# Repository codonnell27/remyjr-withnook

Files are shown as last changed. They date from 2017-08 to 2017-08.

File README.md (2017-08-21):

# remyjr-withnook
Remy Jr autonomous robot using raspberry pi, nook, and various sensors

## Launching 

If launching on the original remyJr, these are the only necessary steps. If launching on a different system, Dependencies & Setup (see below) has a list of packages that need to be on the raspberry pi and nook, while System Dependent Variables (see below) has a list of variables in the remyJr package code that might need to be changed.

 There are two launch files:
 
 driveremy.launch - Launch file for driving without sounds.
 
 loud_drive.launch - Launch file for driving with sounds. Before launching the output speaker must be manually set. For example:
 
 ```bash
pacmd list-sources | grep -e 'name:'
  name: <alsa_output.usb-C-Media_Electronics_Inc._USB_Audio_Device-00.analog-stereo.monitor>
pacmd set-default-source alsa_output.usb-C-Media_Electronics_Inc._USB_Audio_Device-00.analog-stereo.monitor
pacmd list-sinks | grep -e 'name:'
  name: <alsa_output.usb-C-Media_Electronics_Inc._USB_Audio_Device-00.analog-stereo>
pacmd set-default-sink alsa_output.usb-C-Media_Electronics_Inc._USB_Audio_Device-00.analog-stereo

 ```

To launch one of these files (launch from the nook):
```bash
source devel/setup.bash
roslaunch remyJr driveremy.launch
```

## Dependencies & Setup

The remyJr package needs to be on both the nook and the raspberry pi.

It depends on the ros packages rospy, std-msgs, and sound_play. It also has the following non-ros dependencies for the sensors:

##### BNO055 

This package needs to be on the raspberry pi.

The package used can be found here: https://github.com/adafruit/Adafruit_Python_BNO055    

Adafruit's installation/setup instructions can be found here: https://learn.adafruit.com/bno055-absolute-orientation-sensor-with-raspberry-pi-and-beaglebone-black/overview

##### PCA9685 

This package needs to be on the raspberry pi.

The package used can be found here: https://github.com/adafruit/Adafruit_Python_PCA9685  

Adafruit's setup/installation instructions can be found here: https://learn.adafruit.com/adafruit-16-channel-servo-driver-with-raspberry-pi/overview

##### MCP3008  

This package needs to be on the raspberry pi.

The package used can be found here: https://github.com/adafruit/Adafruit_Python_MCP3008

Adafruit's setup/installation instructions can be found here: https://learn.adafruit.com/raspberry-pi-analog-to-digital-converters/mcp3008

In this project, the software SPI connection from Adafruit's setup instructions was used.

##### VL53L0X 

This package needs to be on the raspberry pi.

The package used can be found here, as well as installation instructions: https://github.com/johnbryanmoore/VL53L0X_rasp_python  

The raspberry pi initially had trouble locating the vl53l0x_python.so file. Creating the directory /home/pi/bin and copying the vl53l0x_python.so file into it fixed the problem.

##### Sounds

Sounds used in the project are stored in the misc folder of remyJr. They must be moved to the sound_play/sounds in the sound_play package on the nook to be played. 

##### Raspberry Pi
 
 SSH and i2c must be enabled on the raspberry pi.

## System Dependent Variables

If this is build on another system, the following variables and files must be changed to reflect the new system's connections:

remyJr/launch/driveremy.launch - The address, username, address to env.sh, and password of the raspberry pi may need to be updated.

remyJr/misc/env.sh - ROS_IP and ROS_MASTER_URI must be changed to reflect the address of the nook. ROS_HOSTNAME must be changed to reflect the address of the pi. This file must also be moved to the the devel directory in the workspace directory on the raspberry pi (ex: ~/catkin_ws/devel).

remyJr/scripts/tof_watch.py - f_shutdown_pin and b_shutdown_pin must be changed to the shutdown pins of the time-of-flight sensors. The floor distance variables may also need to be changed depending on the location of the tof sensors.

remyJr/scripts/sonar_watch.py - The software SPI connection pins must be change to reflect the connections between the raspberry pi and the ADC. ADC channel numbers must be changed to reflect channel connections of the sonars and orientation of the array. Finally, sonar_array_trig_pin must be changed to reflect the raspberry pi pin it is connected to.

remyJr/scripts/imu_watch.py - The reset_pin, level_grav_x, and jump_threshold must be changed to reflect the new setup. 

remyJr/scripts/control_motors.py - drivePin and turnPin must be changed to reflect the connections between the motor drivers and the PCA9658.

remyJr/scripts/bump_watch.py - The software SPI connection pins must be change to reflect the connections between the raspberry pi and the ADC. ADC channel numbers must be changed to reflect channel connections of the Joystick.

## Electrical Components used:

1 Raspberry Pi - used to read sensor data and drive motors

1 Nook - used for decision making and graphic sensor and motion data, since the raspberry pi has limited processing power

8 LV-MaxSonar_EZ1 Sonar sensors - used for object detection and to inform descisions as to which direction the robot should drive

2 MCP3008 ADC - One is used in conjunction with the sonars to convert data into a form readable by the raspberry pi; the other does the same for the joystick

2 VL53L0X time-of-flight sensors - used for cliff detection directly in front and behind the robot

1 BNO055 IMU with sensor fustion - used to determine if the robot is level

1 PCA9685 Servo Motor Driver - used to fake an RC signal that is used to command the motor drivers

1 Sunfounder Joystick - used in conjunction with bump skirt to detect if the robot has hit anything

1 USB speaker (optional) - used to make a squeaky toy noise when the robot hits something

## Circuit 

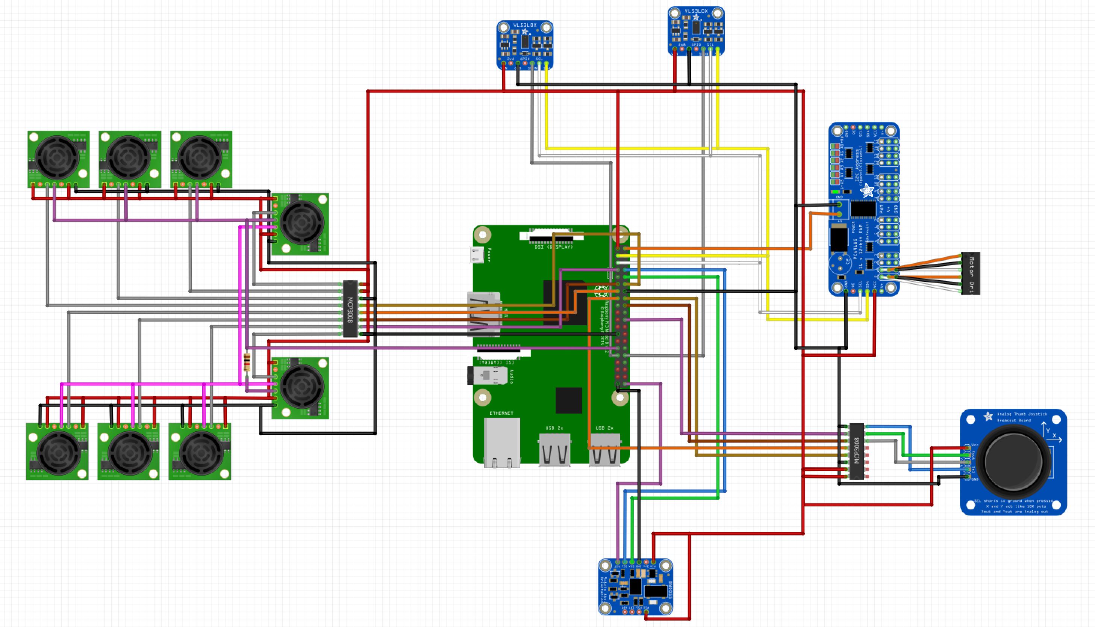
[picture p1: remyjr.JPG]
remyjr circuit diagram


The joystick pictured above is not the joystick used, but it has the same connections.

The sonar array must be arranged so that the sonars facing front, left, right, and back are triggered by the same signal and the sonars facing front right, front left, back left, and back right are triggered by a different signal. This means that no sonar with a purple wire to it's RX pin in the above image should be next to another sonar with a purple RX wire. The same holds true for pink RX wires.

The imu should be placed so that the breakout board is level with the base of the robot and longest sides are on the left and right. (There doesn't seem to be any axis markings on the chip...)

If the raspberry pi is not connected to power via micro usb but the motor drivers are powered, the raspberry pi will power itself via gpio, which leaved it open to frying itself. So be careful when testing the motor drivers that the raspberry pi and PCM9685 is not connected to the motor drivers!

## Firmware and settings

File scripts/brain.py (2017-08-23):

#!/usr/bin/env python
from __future__ import division
from remyJr.msg import sensor_status
from remyJr.msg import imu_data
from remyJr.msg import tof_data
from remyJr.msg import current_activity
from remyJr.msg import sonar_array
from remyJr.msg import graphics_data
from remyJr.msg import bump_data
from remyJr.msg import pwm_val
from remyJr.msg import motor_data
import rospy
import time
import math

# both of these variables correspond to array lengths in sonar_data.msg,
# pwm_val.msg and motor_data.msg
num_of_sonar = 8
pwm_command_queue_len = 50

#PWM values
drive_speed_max = 329
drive_speed_min = 301
drive_speed_zero = 315
# upper and lower bounds of the zero range
# these correspond to the lowest PWM values
# that result in the robot acutally driving
# for some reason these don't result in the same speed???
# for turning, a lower <drive_speed_zero_lowlim PWM value
# will result in a clockwise turn
drive_speed_zero_uplim = 325
drive_speed_zero_lowlim = 305

# together these control how fast the robot accelerates
# accel_const determines the slope of the acceleration curve
# it must be between 0 and 1
# sleep_time (in seconds) determines the time the motors rest between changing PWM values
accel_const = 0.2
sleep_time = 0.07

#determines how fast the robot turns when edgefinding
# edgefind_speed must be between -1 and 1 (a negative number
# will result in the robot turning in the opposite direction)
edgefind_speed = 0.35

# how fast the robot turns when avoiding obstacles
# a smaller value is usually better to avoid overshooting
obstacle_avoidance_speed = 0.1

# the angle the robot tries to keep edges on while edgefinding
right_angle = 90
# these next two values control what the robot considers to be within
# an acceptable range of right_angle
# right_side_width is the number of degrees (centered around right_angle)
# that the robot will consider to be ok when edgefinding
# i.e. when the "edge" is within that range, the robot will drive straight
# instead of turning
right_side_width = 90
right_side_up_lim = (right_angle + (right_side_width/2))
right_side_low_lim = (right_angle -(right_side_width/2))
right_side_opposite = (360-right_angle)

# the robot ignores distances greater than this while edgefinding (in cm)
edge_dis = 100
# distances within this (in cm, so ~1 ft) are not accurately read by the sonar
deadzone = 30
# approx. distance (in cm) that the front sticks out from the front sonar
front_distance = 45
# when the front sonar reads a distance closer than this (in cm)
# the robot won't drive straight. Must be greater then 30cm for accurate reading
tooCloseDis = 60

# this value is compared to how_close to determine if the space is too crowded to edgefind
# how_close is a value (calculated later) between 0 and 1
# 0 being that the robot is in a very confined space and 1 being
# that all sonar are reading a distance greater than edge_dis
# when how_close is less than close_quarters_edgefinding_lim then the robot won't edgefind
# it will just drive straight until it finds and obstacle or it is no longer in such a
# confined space
close_quarters_edgefinding_lim = 0.6

def setup():
	global  motor_change_num, current_l, sonar_dis, x_cord, y_cord, isAvoiding, immediate_danger_f, immediate_danger_b
        global f_sonar, f_r_sonar, r_sonar, b_r_sonar, b_sonar, b_l_sonar, l_sonar, f_l_sonar, tof_drive_ok_f, tof_drive_ok_b
	global avoid_direction_count, avoid_direction, sensor_ok, current_act, is_level, r_bump, l_bump
	global danger_prevented, f_bump, b_bump, current_a, avoidance_count, found_far_away, pwm_command_num, pwm_publish_count, last_pwm_command_num
	#these values represent the order in which seach sonar's data is sent
        f_sonar = 0
        f_r_sonar = 1
        r_sonar = 2
        b_r_sonar = 3
        b_sonar = 4
        b_l_sonar = 5
        l_sonar = 6
        f_l_sonar = 7
	# this is a count to ensure that the robot varies which direction it turns
	# when avoiding obstacles
	avoid_direction_count = 0
	#this indicates the direction the robot will turn when avoiding obstacles
	avoid_direction = 1
	# this count ensures that the robot changes the direction it tries turning periodically
	# only for when it's avoiding obstacles
	# helps keep the robot from getting stuck
	avoidance_count = 0

        rospy.init_node('robot_brain')
        global pub1, pub2, pub3
        pub1=rospy.Publisher('remyjr/motion_data', graphics_data, queue_size=1)
        pub2=rospy.Publisher('remyjr/current_activity', current_activity, queue_size=1)
        pub3=rospy.Publisher('remyjr/pwm_val', pwm_val, queue_size = 3)

	# these keep track of how many pwm commands this node has sent and help other
	# nodes keep track of whether a command has been followed by the robot
	last_pwm_command_num = -1
	pwm_command_num = 0
	pwm_publish_count = 0

	#these are true when there is a cliff in front or behind the robot
	tof_drive_ok_f = False
	tof_drive_ok_b = False

	# true when the setMotors function prevents the robot from moving due to immediate obstacles
	danger_prevented = False

	# true when the bump sensor has detected that the robot has run into something
	b_bump = False
	f_bump = False
	r_bump = False
	l_bump = False

	# true when there is an immediate danger to the robot directly in front or behing
	# i.e. close object, cliff, bump. When true, the motors are prevented
	# from driving in that direction.
	immediate_danger_f = False
	immediate_danger_b = False

	# False when the IMU is no longer level
	is_level = True
	# True when the sensor_watch node thinks that all sensors are online and working
	sensor_ok = False

	# True when the robot is facing the direction with the furthest objects
	found_far_away = False

	# for troubleshooting/monitoring  purposes, this variable is published to a topic
	current_act = 'starting up'

	# the drive(l) or turn(a) value that the motor is using (between -1 and 1)
	current_l = 0
	current_a = 0

	#holds the distances for each sonar
	sonar_dis = [0]*num_of_sonar
	# holds the x- an y-coordinates of objects detected by each sonar
	x_cord = [0]*num_of_sonar
	y_cord = [0]*num_of_sonar

	# calculates some data about the position of the robot
	avgCord()

	# true when the robot is turning to edgefind. Used to control how long the robot
	# sleeps between changing pwm values
	isAvoiding = False

	setMotors(0,0) #so that the robot isn't moving at startup

def accelerate(drive_target, turn_target):
	# changes the speed of the motor with a fixed max rate (determined by accel_const)
	# when the setMotors function prevent the robot from driving, which happens when
	# there is an immediate danger in front/behind the robot, this function stops trying to accelerate
	# gradually accelerates both the linear acceleration and angular acceleration
	global current_l, danger_prevented, current_a
	if (drive_target > current_l) & (turn_target > current_a):
		while (current_l < drive_target) & (turn_target > current_a) & (not danger_prevented):
              		setMotors(current_l, current_a)
			current_l = current_l + accel_const
			current_a = current_a + accel_const
		while (current_l < drive_target) & (turn_target >= current_a) & (not danger_prevented):
			# for when either the current_l or the current_a reaches the target before the other
                        setMotors(current_l, turn_target)
                        current_l = current_l + accel_const
                while (current_l >= drive_target) & (turn_target > current_a) & (not danger_prevented):
                        setMotors(drive_target, current_a)
                        current_a += accel_const

        elif (drive_target > current_l) & (turn_target <= current_a):
                while (current_l < drive_target) & (turn_target < current_a) & (not danger_prevented):
                        setMotors(current_l, current_a)
                        current_l = current_l + accel_const
                        current_a = current_a - accel_const
                while (current_l < drive_target) & (turn_target >= current_a) & (not danger_prevented):
                        setMotors(current_l, turn_target)
                        current_l = current_l + accel_const
                while (current_l >= drive_target) & (turn_target < current_a) & (not danger_prevented):
                        setMotors(drive_target, current_a)
                        current_a = current_a - accel_const

        elif (drive_target <= current_l) & (turn_target > current_a):
                while (current_l > drive_target) & (turn_target > current_a) & (not danger_prevented):
                        setMotors(current_l, current_a)
                        current_l = current_l - accel_const
                        current_a = current_a + accel_const
                while (current_l > drive_target) & (turn_target <= current_a) & (not danger_prevented):
                        setMotors(current_l, turn_target)
                        current_l = current_l - accel_const
                while (current_l <= drive_target) & (turn_target > current_a) & (not danger_prevented):
                        setMotors(drive_target, current_a)
                        current_a = current_a + accel_const

        if (drive_target < current_l) & (turn_target < current_a):
                while (current_l > drive_target) & (turn_target < current_a) & (not danger_prevented):
                        setMotors(current_l, current_a)
                        current_l = current_l - accel_const
                        current_a = current_a - accel_const
                while (current_l > drive_target) & (turn_target >= current_a) & (not danger_prevented):
                        setMotors(current_l, turn_target)
                        current_l = current_l - accel_const
                while (current_l <= drive_target) & (turn_target < current_a) & (not danger_prevented):
                        setMotors(drive_target, current_a)
                        current_a = current_a - accel_const

	if not danger_prevented:
		current_l = drive_target
		current_a = turn_target
	danger_prevented = False
	setMotors(current_l, current_a)

def setMotors(joy_drive, joy_turn):
	#sets the motors to a new PWM by sending the correct pwm value to the motor controls on the raspberry pi
	global  drive_pwm, current_act, danger_prevented, current_a, current_l, turn_pwm, pwm_command_num
	# these next lines prevent the robot from driving backward or forward when
	# one or more sensors are offline
	if not sensor_ok:
		# the robot stops moving entirely
		joy_drive = 0
		joy_turn = 0
		danger_prevented = True
		current_act = "Waiting for all sensors to come back online"
      	current_l = joy_drive
	current_a = joy_turn
	#  multilyping the joy_dirve by how_close allows the robot to adjust its speed depending on
	# how spacious the area it's currently in is. In a more confined space it will go slower.
	drive_pwm = calcPWM(joy_drive*how_close)
	turn_pwm = calcPWM(joy_turn*how_close)
	pwm_command_num +=1 #so that each pwm command has a distinct number
	publishPWM() #tells the motor driver node what value to set the motors to
	time.sleep(sleep_time)

def calcPWM(joy_value):
	#calculates the PWM value for a joystick value (between -1 and 1)
	#skips the range of zero PWM values unless joy_value is zero
	# since the motor drivers only take int PWM values, only returns int values
	# so the range of value is limited
	if joy_value > 1:
		# prevents the robot from exceding the max and min speeds
		joy_value = 1
	elif joy_value < -1:
		joy_value = -1
        if joy_value > 0:
                pwm_val = int (joy_value *(drive_speed_max - drive_speed_zero_uplim) + drive_speed_zero_uplim)
		if pwm_val > drive_speed_max:
			pwm_val = drive_speed_max
        elif joy_value < 0:
                pwm_val = int (joy_value *(drive_speed_zero_lowlim - drive_speed_min) + drive_speed_zero_lowlim)
		if pwm_val < drive_speed_min:
			pwm_val = drive_speed_min
        else:
                pwm_val = drive_speed_zero
        return pwm_val

def goFarAway():
        # spins the robot to the direction where the sonars are reading the furthest distance
        # if it's already facing the furthest distance it drives forward
        global isAvoiding, current_act, avoidance_direction, found_far_away
        isAvoiding=True
	if (far_direction == 0) | found_far_away:
		accelerate(1,0)
		found_far_away  =True
		current_act = "Driving far away from you"
        elif (far_direction >= 4):
                accelerate(0, 1*edgefind_speed)
		avoidance_direction = 1
		found_far_away = False
                current_act = "trying to get away from you"
        elif (far_direction <= 3 ):
                accelerate(0, -1*edgefind_speed)
		avoidance_direction = -1
		found_far_away = False
		current_act = "trying to get away from you"
	else:
		found_far_away = False
		current_act = "something broke - far away is at %f sonar" % far_direction
        isAvoiding = False

def edgefindTurn():
	#decides whether the robot is facing the right direction and which direction to turn if it's not
	# "right direction" being that the edge is in the range determined by right_direction and other constants
	global isAvoiding, current_act
	isAvoiding = True
	if (weighted_angle_avg < right_side_low_lim )  | (weighted_angle_avg > right_side_opposite):
		accelerate(0, edgefind_speed)
		current_act = "edgefinding - turning %f" %edgefind_speed
	elif (weighted_angle_avg <= right_side_opposite )  & (weighted_angle_avg > right_side_up_lim):
                accelerate(0, -1*edgefind_speed)
                current_act = "edgefinding - turning %f" %(-1*edgefind_speed)
	else:
		current_act =  "Found edge!!! - driving"
		accelerate(1,0)
	isAvoiding = False

def reverse(go_in_direction):
	# more of a reverse and turn
	# if the robot needs to back up and find a new course
	# go_in_direction is -1 if it needs to back up (obstacle in front)
	# or 1 if it needs to go straight (obstacle behind)
	global isAvoiding, current_act, avoidance_count
	isAvoiding = True
	c_l = abs(current_l)
	if (c_l < 0.5) & ((not is_level) | f_bump | (not tof_drive_ok_f)):
		# this is to ensure that the robot always backs up if
		# it's not level or if it hits something in front or there is a cliff
		c_l = 0.5
	elif (c_l < 0.5) & ( b_bump | (not tof_drive_ok_b)):
		# to ensure that the robot always drives forward if it
		# hits something behind or if there is a cliff
		c_l = 0.5
	if avoidance_count >= 2:
		# if the robot has been trying to turn to avoid the same obstacles for a while
		# and has switched the directions it's turning to try and avoid the obstacle at
		# at least five times it backs up instead
		c_l = 0.5
		current_act= "unable to turn successfully, reversing"
		avoidance_count = 0
	accelerate(go_in_direction, avoid_direction*obstacle_avoidance_speed)
	time.sleep(0.4) #ensures the robot goes far enough away from the obstacle
	updateAvoidDirection()
	if go_in_direction*abs(c_l) !=0:
		accelerate(0,0)
	isAvoiding = False

def updateAvoidDirection():
	# every once in a while, this switches the direction it turns when avoiding obstacles
	# this helps prevent the robot from getting suck
	# avoid_direction is +1 when it turns clockwise and -1 when it turns counterclockwise
	global avoid_direction, avoid_direction_count, avoidance_count
	if avoid_direction_count >= 15:
		avoid_direction = -avoid_direction
		avoid_direction_count = 0
		avoidance_count +=1
	else:
		avoid_direction_count +=1

def motion():
	#main driving function
	global current_act, avoidance_count,avoid_direction, found_far_away
	current_activity = "calculating motion"
	sensorListener()
	avgCord()
	if not sensor_ok:
		#one or more of the sensors are down, so it stops and waits for the sensors to come online again
		accelerate(0,0)
		found_far_away = False
		avoidance_count = 0 #resets this count since the robot did not have to reverse
		current_act  = "waiting for all sensors to come online again"
	elif ((not tof_drive_ok_f) & (not tof_drive_ok_b)):
		#stops and turns if there are cliffs in front and back
                current_act = "cliff detected in front and behind - %f" % (avoid_direction*obstacle_avoidance_speed)
		reverse(0)
		found_far_away = False
	elif ((not tof_drive_ok_b) | (b_bump)):
		#if there is a cliff behind or it ran into something, it stops, goes forward, and turns
		reverse(1)
		found_far_away = False
		current_act = "hazard behind the robot, driving forward %f" % (avoid_direction*obstacle_avoidance_speed)
        elif ((not tof_drive_ok_f)| (f_bump)) | (not is_level):
                # stops, backs up, and turns if there is a cliff, it ran into something,
                # or is not level.
                reverse(-1)
                found_far_away = False
                current_act = "hazard is in front - reversing %f" % (avoid_direction*obstacle_avoidance_speed)
        elif r_bump | l_bump:
                if r_bump:
                        current_act = "robot hit something on the right"
                elif l_bump:
                        current_act = "robot hit something on the left, reversing"
                reverse(0.1)
                found_far_away = False
	elif (sonar_dis[f_sonar] < tooCloseDis)| (sonar_dis[f_l_sonar] < deadzone) | (sonar_dis[f_r_sonar] < deadzone):
		#when there is something in front of the robot it stops and turns
		current_act = "obstacle - stopping and turning %f" % (avoid_direction*obstacle_avoidance_speed)
		reverse(0)
		found_far_away = False
	elif (how_close <= close_quarters_edgefinding_lim):
		# when the robot is in a tight space it tries to find the direction where the sonars are reporting
		# the farthest object and go in that direction
		avoidance_count = 0
		goFarAway()
	elif (weighted_dis_avg > deadzone) & (weighted_dis_avg < edge_dis) & (how_close > close_quarters_edgefinding_lim):
		#so the robot only edgefinds when it is in a relatively open space
		edgefindTurn()
		found_far_away = False
                avoidance_count = 0 #resets the avoidance count since it didn't need to avoid anything
	else:
		# when it's in a super open space or there are no edges concentrated on one side
		# it just drives straight
		current_act = "driving for funsies"
                avoidance_count = 0 #resetting this, since it didn't avoid anything
		accelerate(1,0)

def convertCartesian():
	#converts sonar data to cartesian coordinates
	# front sonar is zero degrees (assuming data is received from sonar_array node
	#in counterclockwise order beginning from the front sonar
	global x_cord, y_cord
	for i in range(len(sonar_dis)):
		x_cord[i] = sonar_dis[i] * math.sin(i * math.pi/4)
		y_cord[i] = sonar_dis[i] * math.cos(i *math.pi/4)

def avgCord():
	# calculates the weighted average of the sonar data for edgefinding
	# and determines how confined the space it's in is
	global x_avg, y_avg, weighted_dis_avg, weighted_angle_avg
	x_avg = 0 #hold the cartesian coordinates for each sonar's data
	y_avg = 0
	# these two points are polar coordinates of the average of sonar data within a certain radius band
	weighted_dis_avg = 0 #the distance of an average of the points within a certain radius range
	weighted_angle_avg = 0 #the angle of an average of the points within that certain radius range
	count = 0
	angle_sum = 0
	convertCartesian()
	for i in range(len(sonar_dis)):
		# calculates the weighted average of the sonar detected objects
		# it takes a weighted average of those objects
		# if the object is closer then deadzone or further away than the edge_distance it
		# ignores the object
		# other objects have a weight inversly proportional to the distance the object is
		# from the object
		if (sonar_dis[i] < edge_dis) & (sonar_dis[i] > deadzone):
			weight = (abs(edge_dis - sonar_dis[i])) **2.5
			count = count + weight
			x_avg = x_avg + x_cord[i]*(weight)
 			y_avg = y_avg + y_cord[i]*(weight)
			angle_sum = angle_sum + i *45*(weight)
	if (count != 0):
		x_avg = x_avg/count
		y_avg = y_avg/count
		weighted_angle_avg = angle_sum / count
	else:
		weighted_angle_avg = 0
	weighted_dis_avg = math.hypot(x_avg, y_avg)

        #determines how open the space it's in is
        #i.e. middle of desk spaces or not
        # the smaller the value of how_close the more confined the area
	# how_close is compared to close_quarters_edgefinding_lim (a constant)
	# to determine if the space is too cramped to edgefind
        global how_close
        how_close = 0
        for i in range(len(sonar_dis)):
                if (sonar_dis[i] <= edge_dis) & (sonar_dis[i] > deadzone):
                        how_close += (sonar_dis[i]/edge_dis)**10
                elif (sonar_dis[i] > edge_dis):
                        how_close +=1
        how_close = how_close /len(sonar_dis)

	# figures out which sonar is sensing the furthest direction
	# so that the robot can drive in that direction if the space
	# is too tight for edgefinding
        global far_direction
        far_direction = 0
        far_dis = 0
        for i in range(num_of_sonar):
                if sonar_dis[i] > far_dis:
                        far_direction = i
                        far_dis = sonar_dis[i]

def sonarlistener(data):
        #listens for the sonar data
        global sonar_dis
        sonar_dis = data.distances

def imuListener(data):
	# listens to see if the imu thinks the robot is level
        global is_level
        is_level = data.is_level

def sensorStatusListener(data):
        #this node checks whether the sensors are online and reports True if all sensors are working
        global sensor_ok
        sensor_ok = data.sensor_system_status

def tofListener(data):
        # the time of flight sensor checks to see if there is
        # a cliff/sudden drop of floor in front or behind the robot
        global tof_drive_ok_f, tof_drive_ok_b
        tof_drive_ok_f = data.drive_front_ok
        tof_drive_ok_b = data.drive_back_ok
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

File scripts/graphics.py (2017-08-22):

#!/usr/bin/env python
from remyJr.msg import graphics_data
from remyJr.msg import graphics_queues
import rospy
import time
import math
import matplotlib.pyplot as plt
import numpy as np

#holds the x and y coordinates of unit vectors representing each direction a sonar is facing
sonar_x_cords = [0.0, 1/1.4142, 1.0, 1/1.4142, 0.0, -1/1.4142, -1.0, -1/1.4142, 0.0]
sonar_y_cords = [1.0, 1/1.4142, 0.0, -1/1.4142, -1.0, -1/1.4142, 0.0, 1/1.4142, 1.0]

# this value must be the same as the length of the distances array in sonar_array.msg
num_of_sonar = 8

# this value must be the same as the length of the arrays that hold the
# pwm commands in motor_data.msg and pwm_val.msg
motor_queue_len = 100

def setup():
	global sonar_dis, x_cord, y_cord, x_avg, y_avg, edgeDis, deadzone, tooCloseDis, pwm_zero_min
	global close_quarters_queue, edgefinding_lim_y, pwm_zero_max
        global pwm_command_drive_queue, pwm_command_turn_queue, pwm_command_num_queue, pwm_zero_max_y
        global motor_val_turn_queue, motor_val_drive_queue, motor_val_num_queue, pwm_max, pwm_min, pwm_zero_min_y

	# these next arrays hold values used to graph  the brain pwm commands vs
	# what the motor driver are following
	motor_val_turn_queue = np.zeros(motor_queue_len)
	motor_val_drive_queue = np.zeros(motor_queue_len)
	motor_val_num_queue = np.zeros(motor_queue_len)
        pwm_command_turn_queue = np.zeros(motor_queue_len)
        pwm_command_drive_queue = np.zeros(motor_queue_len)
        pwm_command_num_queue = np.zeros(motor_queue_len)

	# these variables hold values used to visualize how tight the space the robot is in
	close_quarters_queue = np.zeros(motor_queue_len)
	edgefinding_lim_y = np.zeros(motor_queue_len)
	sonar_dis = [0]*num_of_sonar #holds the distances for each sonar
	x_cord = [0]*num_of_sonar #holds the x-cordinates for objects detected by each sonar
	y_cord = [0]*num_of_sonar #holds the y-cordinates for objects deteced by each sonar
	x_avg = 0 #weighted average of the x-coordinates of the sonar data, received from another node
	y_avg = 0 #weighted average of the y-coordinates of the sonar data, received from another node
	#these are all received from another node and represent the radius of different zones used in navigating
	edgeDis = 0
	deadzone = 0
	tooCloseDis = 0
	pwm_max = 0
	pwm_min = 0
	pwm_zero_max = 0
	pwm_zero_min = 0
	pwm_zero_min_y = np.zeros(motor_queue_len)
	pwm_zero_max_y = np.zeros(motor_queue_len)
	plt.ion()
        fig = plt.figure(figsize=(35,17), dpi=45)
	findRings() #calculates the coordinates that represent the different zones used in navigating

def getRingCordX(dis): #calcluates the x-cordinates representing a radius around the robot
	cord = [0]*(num_of_sonar+1)
	for i in range(len(cord)):
		cord[i] = dis * sonar_x_cords[i]
	return cord

def getRingCordY(dis): #calculates the y-coordinates representing a radius around the robot
        cord = [0]*(num_of_sonar + 1)
        for i in range(len(cord)):
                cord[i] = dis * sonar_y_cords[i]
        return cord

def findRings(): #calculates the coordiates representing various regions around the robot
	global deadzone_x, deadzone_y, tooClose_x, pwm_zero_min_y, tooClose_y, edge_x, edge_y, pwm_zero_max_y
	deadzone_x = getRingCordX(deadzone)
        deadzone_y = getRingCordY(deadzone)
	tooClose_x = getRingCordX(tooCloseDis)
        tooClose_y = getRingCordY(tooCloseDis)
        edge_x = getRingCordX( edgeDis)
        edge_y = getRingCordY(edgeDis)
	pwm_zero_max_y = np.ones(motor_queue_len)*(pwm_zero_max -1)
	pwm_zero_min_y = np.ones(motor_queue_len)*(pwm_zero_min+1)

def plotData(): #plots the data

	plt.clf()
	if pwm_command_num_queue[0] ==0:
		xlim_low = pwm_command_num_queue[motor_queue_len -1] -motor_queue_len
	else:
		xlim_low = pwm_command_num_queue[0]

	# graphs the close quarters value, which represents how tight a space the robot is in
	# if this value is above the edgefinding threshold, the robot will edgefind
	# if it's below, the robot will just pick the direction with the furthest object and drive towards that
        plt.subplot2grid((14,2),(0,0), rowspan=4, colspan=1)
        plt.ylim(0,1)
        plt.xlim(xlim_low, pwm_command_num_queue[motor_queue_len -1]+2)
        plt.plot(pwm_command_num_queue, edgefinding_lim_y, color="red", linewidth=3, label="Edgefinging Threshold")
        plt.plot(pwm_command_num_queue, close_quarters_queue, color="blue", linewidth =3, label="Close Quarters Value")
	plt.ylabel("Close Quarters Value", fontsize=20)
	plt.title("How Tight a Space the Robot is in", fontsize=20)
	plt.legend(loc='upper left', fontsize=12)

	# graphs the drive pwm values
        # this show the current pwm commands that the brain node sent vs those that the motor driver is following
        # which allows us to easily see if the motor driver is lagging significantly or missing commands
        plt.subplot2grid((14,2), (5,0), rowspan=4, colspan=1)
        plt.xlim(xlim_low, pwm_command_num_queue[motor_queue_len -1]+2)
        plt.ylim(pwm_min -5,pwm_max+5)
	plt.ylabel("PWM Values", fontsize=20)
	plt.xlabel("Command Number", fontsize=20)
        plt.text(pwm_command_num_queue[40], pwm_min, "Backward", fontsize=15)
        plt.text(pwm_command_num_queue[40], pwm_max, "Forward", fontsize=15)
	plt.title("Drive PWM Values - Latest Brain Commands vs Latest Motor Driver Commands", fontsize=20)
	plt.plot(pwm_command_num_queue, pwm_zero_max_y, color="gray", linewidth=1, label="Zero Range Maximum and Minimum")
        plt.plot(pwm_command_num_queue, pwm_zero_min_y, color="gray", linewidth=1)
        plt.plot(pwm_command_num_queue, pwm_command_drive_queue, color="red", linewidth=6, label="Brain Commands")
        plt.plot(motor_val_num_queue, motor_val_drive_queue, color="black", linewidth=2, label="Motor Driver Commands")
	plt.legend(loc='center left', fontsize=12)
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

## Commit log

2017-08-22 Update control_motors.py
    Changed motor frequency
2017-08-22 tweeks to help with motor lagging
